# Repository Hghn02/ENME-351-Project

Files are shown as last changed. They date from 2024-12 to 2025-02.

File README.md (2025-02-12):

# ENME-351-Project

This was a project for my ENME351 class at the University of Maryland. I created an IMU-guided 2-Axis gimbal that had an IR distance sensor and laser diode mounted to it for target sensing. The software for this project was written in Arduino C++ and Processing.

---

## Hardware List
The following components were used in this project:
- **Arduino Uno**
- **BNO055 9-DOF Absolute Orientation IMU Sensor**
- **GP2Y0A21YK0F SHARP IR Distance Sensor**
- **HiLetgo 5V 650nm 5mW Laser Diode**
- **FEETECH Mini Servo FT1117M (x2)**
- **6.0 V, 2200 mAh Rechargeable NiMH Battery (x2)**
- **Breadboard**
- **M3 screws**

---

## How It Works

The IMU-guided 2-Axis gimbal uses a BNO055 9 DOF IMU sensor to detect Euler angles, which are transmitted to the Arduino via I2C. The Arduino processes the IMU data and controls two FEETECH Mini Servos, which adjust the gimbal's pan and tilt angles. The servo control logic is implemented using manual PWM code and allows for simultaneous actuation rather than using the servo.h library. Mounted on the gimbal, the IR distance sensor detects the target's range, while the laser diode pulses based on the distance sensed. The laser diode is controlled through an NPN transistor circuit. The servo motors are powered by two 6.0V rechargeable NiMH batteries, with all components wired through a breadboard.

The accompanying Processing code displays live telemetry data, including orientation angles and distance readings, providing real-time feedback to the user.

---

## Telemetry Window
Here’s a picture of the graphical display window

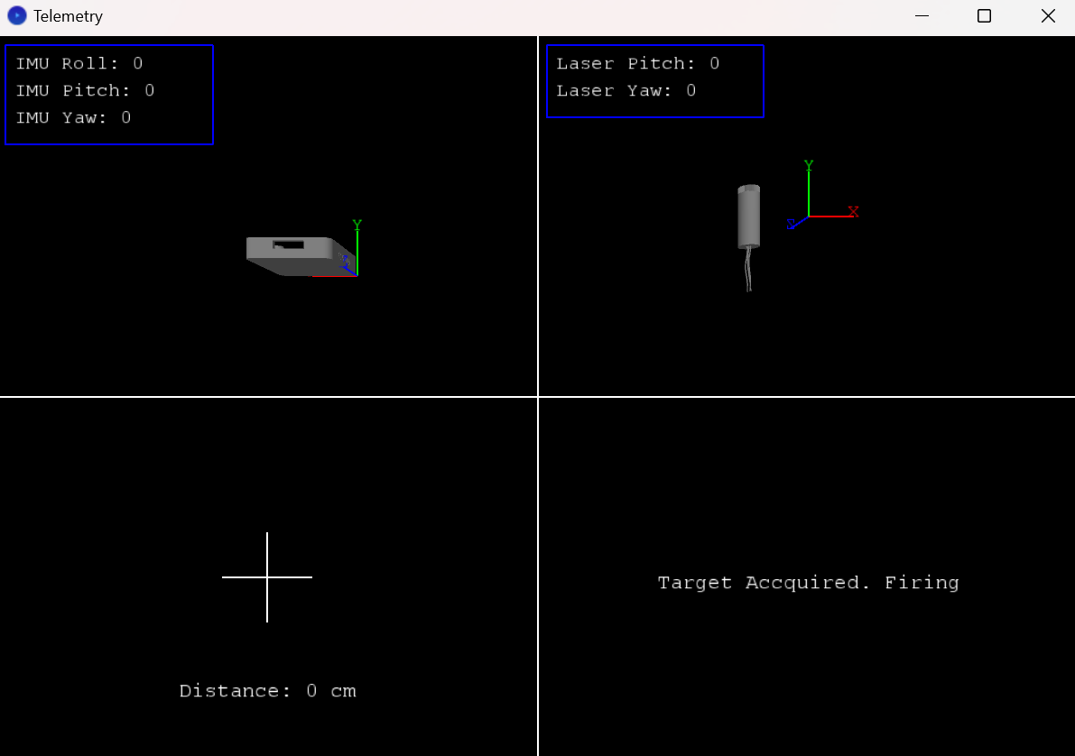
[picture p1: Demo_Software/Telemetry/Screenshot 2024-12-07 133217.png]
Screenshot Placeholder


---

## Demo Video
Watch the project demonstration video here:

Watch the video (https://www.youtube.com/watch?v=X9MKAsoJGBA)

---

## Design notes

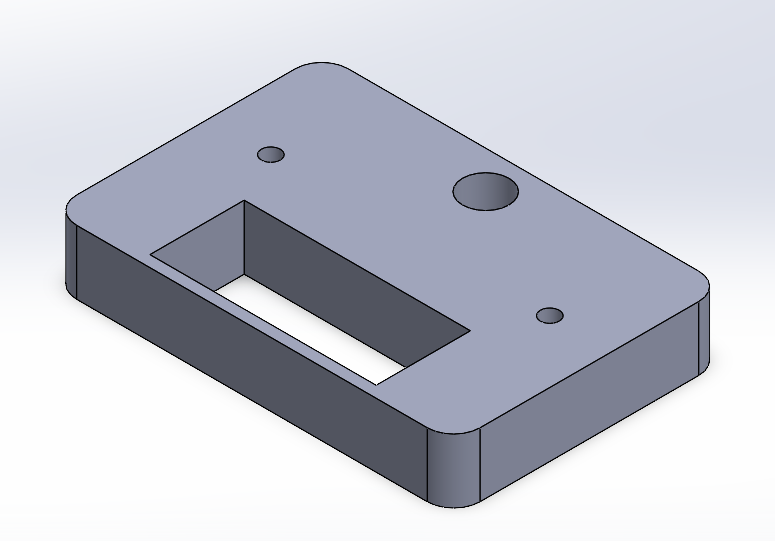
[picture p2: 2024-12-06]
CAD Models/Sensor Mount/Sensor Mount.png

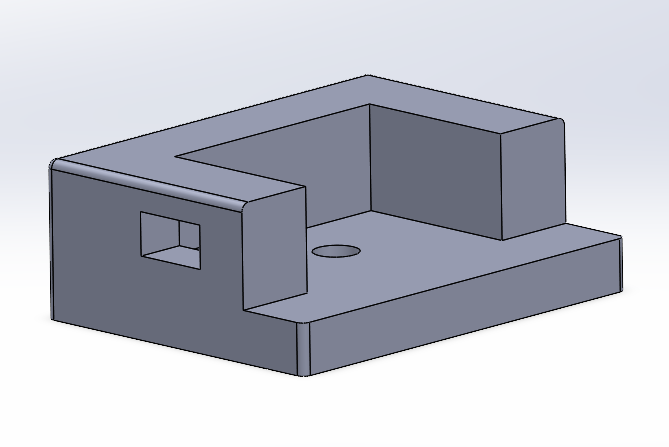
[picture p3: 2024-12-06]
CAD Models/Tilt Servo Mount/Tilt Servo Mount.png

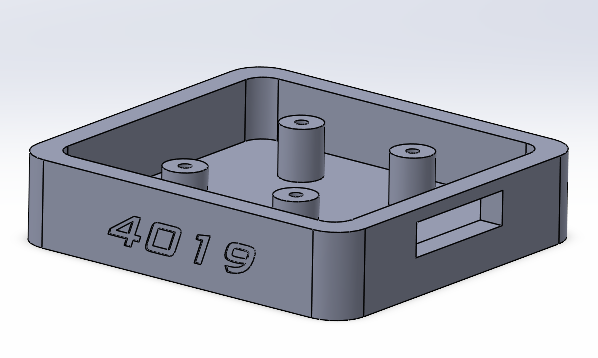
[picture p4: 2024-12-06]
CAD Models/IMU Mount/IMU Mount.png

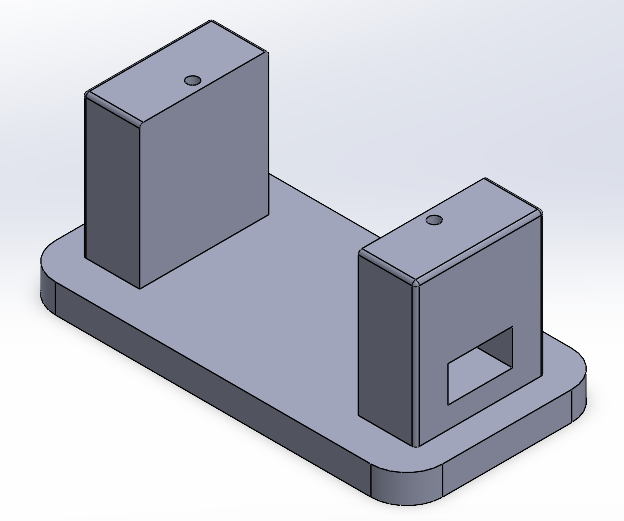
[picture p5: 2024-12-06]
CAD Models/Pan Servo Mount/Pan Servo Mount.png

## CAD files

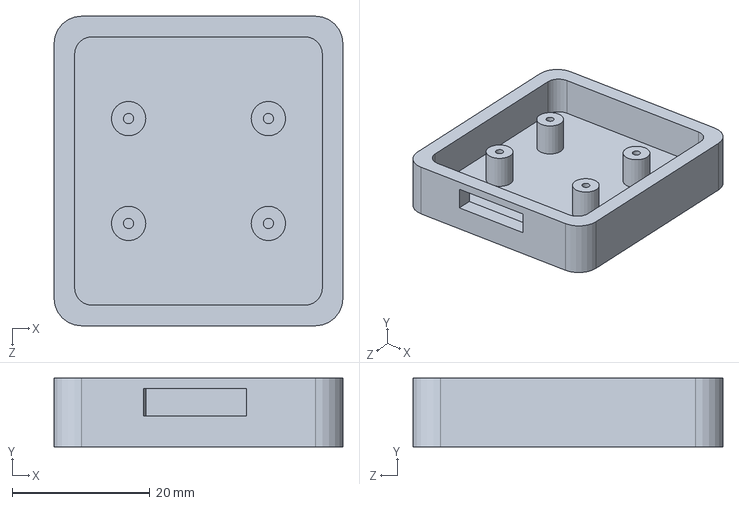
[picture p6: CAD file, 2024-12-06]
CAD Models/IMU Mount/IMU Mount.SLDPRT
42.0 x 10.0 x 45.0 mm

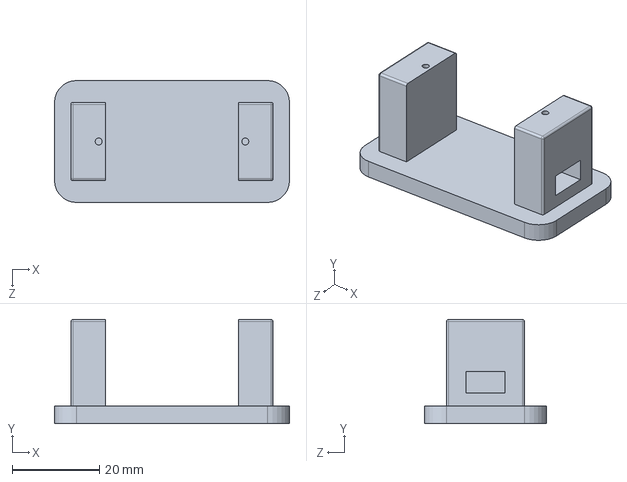
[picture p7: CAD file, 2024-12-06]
CAD Models/Pan Servo Mount/Pan Servo Mount.SLDPRT
54.0 x 23.9 x 28.0 mm

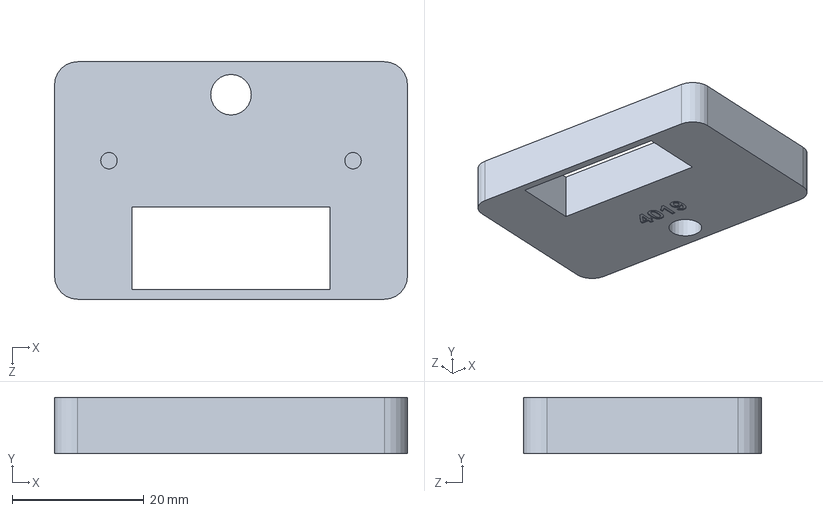
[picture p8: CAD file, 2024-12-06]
CAD Models/Sensor Mount/Sensor Mount.SLDPRT
53.5 x 8.50 x 36.0 mm

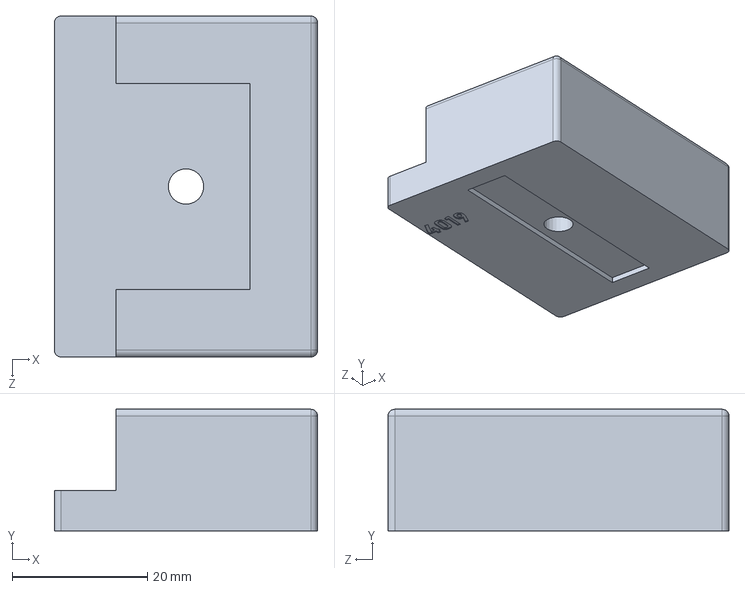
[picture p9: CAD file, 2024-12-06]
CAD Models/Tilt Servo Mount/Tilt Servo Mount.SLDPRT
39.0 x 18.0 x 50.5 mm

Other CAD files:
Demo_Software/Telemetry/ImageToStl.com_imu+mount.obj

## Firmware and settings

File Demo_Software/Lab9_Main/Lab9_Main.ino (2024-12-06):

#include <SharpIR.h> // Importing distance sensor library

// Importing IMU libraries
#include <Wire.h>
#include <Adafruit_Sensor.h>
#include <Adafruit_BNO055.h>
#include <utility/imumaths.h>

#include <math.h> 

// Pin Numbers
int yawServoPin = 5;
int pitchServoPin =6;
int laserPin = 3;
 
// Servo PWM Parameters
const int t_min = 600; // Probably the minimum pulse width (datasheet had listed 900)
const int t_max = 2300; // Probably the maximum pulse width (datasheet had listed 2100)
const int servoPeriod = 20000; // Probably the servo period

// Mapped PWs from from orientation data
int mappedYawPW = 0;
int mappedPitchPW = 0;

// Laser Pulse Parameters
bool laserPulseState =false;

// Global variables for laser timing
unsigned long lastLaserToggle = 0;
bool laserState = false;
const unsigned long PULSE_PERIOD = 1000; 

// IMU Sensor Initialization
Adafruit_BNO055 bno = Adafruit_BNO055(55,0x28);
uint16_t BNO055_SAMPLERATE_DELAY_MS = 100;

// Distance Sensor Initialization
SharpIR sensor( SharpIR::GP2Y0A41SK0F, A0 );

// Function to get distance for IR distance sensor
bool readDistance() {
  // Reading distance to a object
  int distanceToObj = sensor.getDistance();
  Serial.println(distanceToObj);

  // Target in range or not
  if (distanceToObj < 20) {
    return true;
  } else {
    return false;
  }
  
}

// Laser Control Function
void laserPulse(bool state) {
  unsigned long currentMicros = micros();
  
  if (state == true) { 
    // pulse implementation
    if (currentMicros - lastLaserToggle >= (PULSE_PERIOD/500)) { // Toggle every 500 microseconds
      laserState = !laserState;
      digitalWrite(laserPin, laserState);
      lastLaserToggle = currentMicros;
    }
  } else {
    digitalWrite(laserPin,HIGH); // No pulsing just pointing
  }
}

// Control Yaw and Pitch Servos simultaneously
void servoControl() {

  digitalWrite(yawServoPin,HIGH);
  digitalWrite(pitchServoPin, HIGH);
  delayMicroseconds(min(mappedYawPW, mappedPitchPW)); // Wait for the shorter pw

  if (mappedYawPW > mappedPitchPW) {
      digitalWrite(pitchServoPin, LOW); // Turn off the pitch servo
      delayMicroseconds(mappedYawPW - mappedPitchPW); // Wait for the remaining time for yaw
      digitalWrite(yawServoPin, LOW);
  } else {
      digitalWrite(yawServoPin, LOW); // Turn off the yaw servo
      delayMicroseconds(mappedPitchPW - mappedYawPW); // Wait for the remaining time for pitch
      digitalWrite(pitchServoPin, LOW);
  }

    // Ensure the total period is kept
  delayMicroseconds(servoPeriod - max(mappedYawPW, mappedPitchPW));

}

void readIMU() {

  // Fetching orientation and angular velocity data
  // Note the code below (lines 94 - 96) was borrowed from "https://learn.adafruit.com/adafruit-bno055-absolute-orientation-sensor/arduino-code"
  sensors_event_t orientationData, angVelData;
  bno.getEvent(&orientationData,Adafruit_BNO055::VECTOR_EULER);
  //bno.getEvent(&angVelData, Adafruit_BNO055::VECTOR_GYROSCOPE);

  // Rounding yaw and pitch angles
  int yawAngle= round(orientationData.orientation.x);
  int pitchAngle = round(orientationData.orientation.z);
  int rollAngle = round(orientationData.orientation.y);

  // Mapping Euler angles to servo pulse range for actuation
  mappedYawPW = map(yawAngle,0,360,t_min,t_max);
  mappedPitchPW = map(constrain(pitchAngle,-90,0),-90,0,t_min,(t_max/2)+100);
  
  // Calculating actual Servo angles for Telemetry and verification
  int actualYawPW = map(mappedYawPW,t_min,t_max,0,360);
  int actualPitchPW = map(mappedPitchPW,t_min,(t_max/2)+100,-90,0);
  
  // Sending all orientation data over serial port to Processing
  Serial.print(yawAngle);
  Serial.print("\t");
  Serial.print(pitchAngle);
  Serial.print("\t");
  Serial.print(rollAngle);
  Serial.print("\t");
  Serial.print(actualYawPW);
  Serial.print("\t");
  Serial.print(actualPitchPW);
  Serial.print("\t");

}

void setup() {

  // Initializing pins
  Serial.begin(115200);

  pinMode(yawServoPin,OUTPUT);
  pinMode(pitchServoPin,OUTPUT);
  pinMode(laserPin,OUTPUT);

  digitalWrite(laserPin,LOW); 

  
  // Note the code below (lines 139 - 147) was borrowed from "https://learn.adafruit.com/adafruit-bno055-absolute-orientation-sensor/arduino-code"
  /* Initialise the sensor */
  if(!bno.begin())
  {
    /* There was a problem detecting the BNO055 ... check your connections */
    Serial.print("Ooops, no BNO055 detected ... Check your wiring or I2C ADDR!");
    while(1);
  }
  
  delay(1000);
  bno.setExtCrystalUse(true);

}

void loop() {
  // put your main code here, to run repeatedly:
  unsigned long currentTime = micros();

  // Function calls 
  readIMU();
  servoControl();
  bool pulseState = readDistance();  
  laserPulse(pulseState);

  // Timing loop for entire system
  while ((micros() - currentTime) < (BNO055_SAMPLERATE_DELAY_MS * 1000))
  {

  }
}

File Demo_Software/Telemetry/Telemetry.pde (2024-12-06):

import processing.serial.*;

Serial myPort;

// Variables to keep track of orientation
int Roll = 0;
int Pitch = 0;
int Yaw = 0;
int servoYaw = 0;
int servoPitch = 0;
int distance = 0;

// 3D Model objects
PShape imu;
PShape laser;

PFont font;

void setup() {
  printArray(Serial.list());
  myPort = new Serial(this, Serial.list()[0], 115200);
  myPort.clear();
  
  size(1200, 800, P3D); 
  
  // Load IMU mount 3D model
  imu = loadShape("ImageToStl.com_imu+mount.obj"); 
  imu.scale(2);
  
  // Load Laser Diode 3D model which will represent gimbal movement
  laser = loadShape("ImageToStl.com_laser diode module.obj"); 
  laser.scale(2);
  
  // Load custom font
  font = createFont("Courier", 18);
  textFont(font);
  textSize(18);
}

void draw() {
  // Reading in data from serial port
  while (myPort.available() > 0) {
    String inString = myPort.readStringUntil('\n');
    if (inString != null) {
      inString = trim(inString);
      String[] systData = splitTokens(inString, "\t"); // Splitting data based on tabs
      if (systData.length == 6) { 
        Yaw = int(systData[0]);
        Pitch = int(systData[1]);
        Roll = int(systData[2]);
        servoYaw = int(systData[3]);
        servoPitch = int(systData[4]);
        distance = int(systData[5]);
      }
    }
  }

  background(0); // black background
  lights();

  // Split window into 4 squares
  stroke(255); 
  strokeWeight(2);
  line(width / 2, 0, width / 2, height); // Vertical dividing line
  line(0, height / 2, width, height / 2); // Horizontal dividing line

  // IMU Orientation in top left
  pushMatrix();
  translate(width / 3, height / 3, 0); 
  rotateX(radians(Pitch));
  rotateY(radians(Yaw));
  rotateZ(radians(Roll + 180));
  shape(imu);
  drawAxis(50); // Attach axes to IMU
  popMatrix();

  // Blue rectangle outline around IMU readings
  stroke(0, 0, 255); 
  noFill();
  rect(10, 10, 230, 110);

  // IMU Roll, Pitch, Yaw readings
  fill(255); // 
  textAlign(LEFT, CENTER);
  text("IMU Roll: " + Roll, 20, 25);
  text("IMU Pitch: " + Pitch, 20, 55);
  text("IMU Yaw: " + Yaw, 20, 85);

  // Laser Orientation in the top right
  pushMatrix();
  translate(3 * width / 4, height / 4, 0); // Center of top-right quadrant
  rotateX(radians(servoPitch + 180));
  rotateY(-radians(servoYaw));
  shape(laser);
  drawAxis(50); // Attach axes to Laser
  popMatrix();

  // Blue rectangle outline around Laser readings
  stroke(0, 0, 255); // Blue outline
  noFill();
  rect(width / 2 + 10, 10, 240, 80);

  // Laser Pitch and Yaw readings
  fill(255); 
  textAlign(LEFT, CENTER);
  //text("Laser Roll: " + Roll, width / 2 + 20, 25);
  text("Laser Pitch: " + servoPitch, width / 2 + 20, 25);
  text("Laser Yaw: " + servoYaw, width / 2 + 20, 55);

  // Crosshair with Distance Reading in bottom left
  stroke(255); 
  line(width / 4 - 50, 3 * height / 4, width / 4 + 50, 3 * height / 4); // Horizontal line
  line(width / 4, 3 * height / 4 - 50, width / 4, 3 * height / 4 + 50); // Vertical line
  fill(255);
  textAlign(CENTER, CENTER);
  textSize(24);
  text("Distance: " + distance + " cm", width / 4, 3 * height / 4 + 120);

  // Laser Status
  fill(255);
  textAlign(CENTER, CENTER);
  textSize(24);
  
  if (distance < 20) {
    text("Target Accquired. Firing", 3 * width / 4, 3 * height / 4);
  } else {
      text("System Idle. No Target in Range.", 3 * width / 4, 3 * height / 4);
  }
}
// Function to draw the axes attached to the 3D objects
void drawAxis(float size) {
  strokeWeight(2);
  
  // X Axis (Red) -  Pitch
  stroke(255, 0, 0);
  line(0, 0, 0, size, 0, 0);
  pushMatrix();
  translate(size, 0, 0); 
  fill(255, 0, 0); 
  textAlign(CENTER, CENTER);
  textSize(22);
  text("X", 0, 0);
  popMatrix();
  
  // Y Axis (Green) - Yaw
  stroke(0, 255, 0);
  line(0, 0, 0, 0, size, 0);
  pushMatrix();
  translate(0, size, 0); 
  rotateX(radians(180));
  fill(0, 255, 0); 
  textAlign(CENTER, CENTER);
  textSize(22);
  text("Y", 0,-12);
  popMatrix();
  
  // Z Axis (Blue) - Roll
  stroke(0, 0, 255);
  line(0, 0, 0, 0, 0, size);
  pushMatrix();
  translate(0, 0, size);
  fill(0, 0, 255);
  textAlign(CENTER, CENTER);
  textSize(22);
  text("Z", 0, 0);
  popMatrix();
}

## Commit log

2024-12-06 Add files via upload
    Graphical Display in Processing
    [ImageToStl.com_imu+mount.obj]
2024-12-06 Add files via upload
    OBJ files used for Graphical Display
    [ImageToStl.com_imu+mount.obj]
2024-12-06 Folder creation for CAD
2024-12-06 Add files via upload
    SHARP IR Distance Sensor Mount
    [Sensor Mount.SLDPRT]
